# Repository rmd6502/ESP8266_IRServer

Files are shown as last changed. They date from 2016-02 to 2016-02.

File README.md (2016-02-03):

ESP8266 IR Throwie
==================

This takes the concept of the TV-B-Gone one step further
by allowing the device to be controlled with Wifi.

This version hardcodes the wifi parameters, but a future version
will allow use as an Access Point to set up wifi.

You'll need [my fork](https://github.com/rmd6502/IRremoteESP8266) of the IRRemote ESP8266 
library for the Dyson remote protocol support.

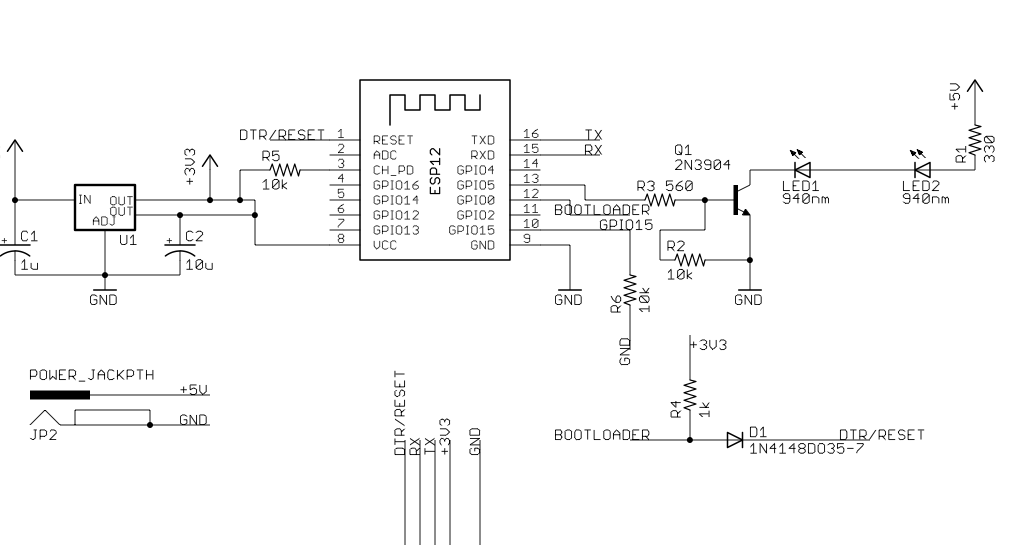
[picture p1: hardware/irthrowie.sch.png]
schematic


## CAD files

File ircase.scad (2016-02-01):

$fn=40;
board_width = 32.72;
board_length = 54.61;
board_height = 2;

module bottom() {
    union() {
        difference() {
            translate([-6.5,-3,0]) cube([42,64,10]);
            translate([-5.5,-2,1]) cube([40,62,9.1]);
            // four mounting screws
            translate([-3.5,1,-0.1]) cylinder(d=3, h=1.2);
            translate([-3.5,49,-0.1]) cylinder(d=3, h=1.2);
            translate([33,1,-0.1]) cylinder(d=3, h=1.2);
            translate([33,49,-0.1]) cylinder(d=3, h=1.2);
            // cutout for power
            translate([-6.6,0,5]) minkowski() {
                cube([2,11,6]);
                rotate([0,90,0]) cylinder(d=2,h=2);
            }
        }
        // mount board to case
        translate([17.55,2.6,1]) difference() {
            cylinder(d=5,h=4);
            cylinder(d=2.8,h=4.1);
        }
        // mount board to case
        translate([28.85,39.4,1]) difference() {
            cylinder(d=5,h=4);
            cylinder(d=2.8,h=4.1);
        }
        //translate([-1.75,0,5]) cube([board_width, board_length, board_height]);
        
        // screwhole for top
        translate([-4,30,0.9]) difference() {
            cylinder(h=9.1,d=4);
            translate([0,0,4]) cylinder(h=5.2,d=2.5);
        }
        translate([33,30,0.9]) difference() {
            cylinder(h=9.1,d=4);
            translate([0,0,4]) cylinder(h=5.2,d=2.5);
        }
    }
}

module top() {
    union() {
        difference() {
            translate([-6.5,-3,14]) cube([42,64,1.3]);
            translate([25.05,5.3,12]) led();
            translate([25.05,12.8,12]) led();
            // Design for the top - deliberately not included
            rotate([0,0,90]) translate ([15.6,53,14.6]) linear_extrude(0.8) resize([35,0,0],auto=true) import("zenith_1937.dxf");
            translate([-4,30,13.9]) cylinder(h=1.5,d=2.7);
            translate([33,30,13.9]) cylinder(h=1.5,d=2.7);
        }
        difference() {
            translate([-5,-1.5,13]) cube([39.5,61.5,1]);
            translate([-4,-0.5,12.9]) cube([37.5,59.5,1.2]);
            translate([-4,30,12.9]) cylinder(h=1.3,d=4.2);
            translate([33,30,12.9]) cylinder(h=1.3,d=4.2);
        }
    }
}

module led() {
    union() {
        cylinder(h=6.1, r=2.6);
        translate([0,0,6.1]) sphere(r=2.6);
        difference() {
            cylinder(r=3.1,h=1);
            translate([2.6, -3, -.1]) cube([2,6,1.2]);
        }
    }
}

bottom();

top();

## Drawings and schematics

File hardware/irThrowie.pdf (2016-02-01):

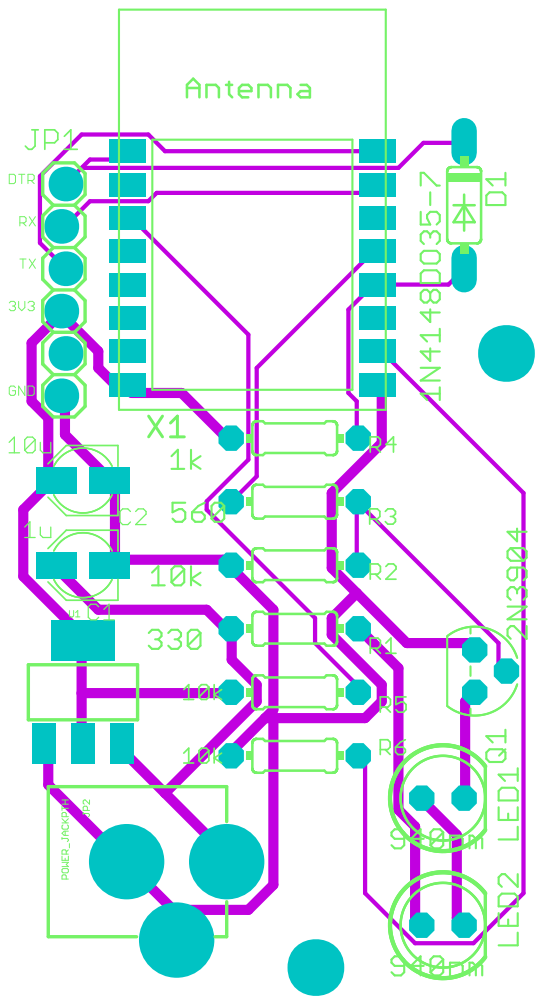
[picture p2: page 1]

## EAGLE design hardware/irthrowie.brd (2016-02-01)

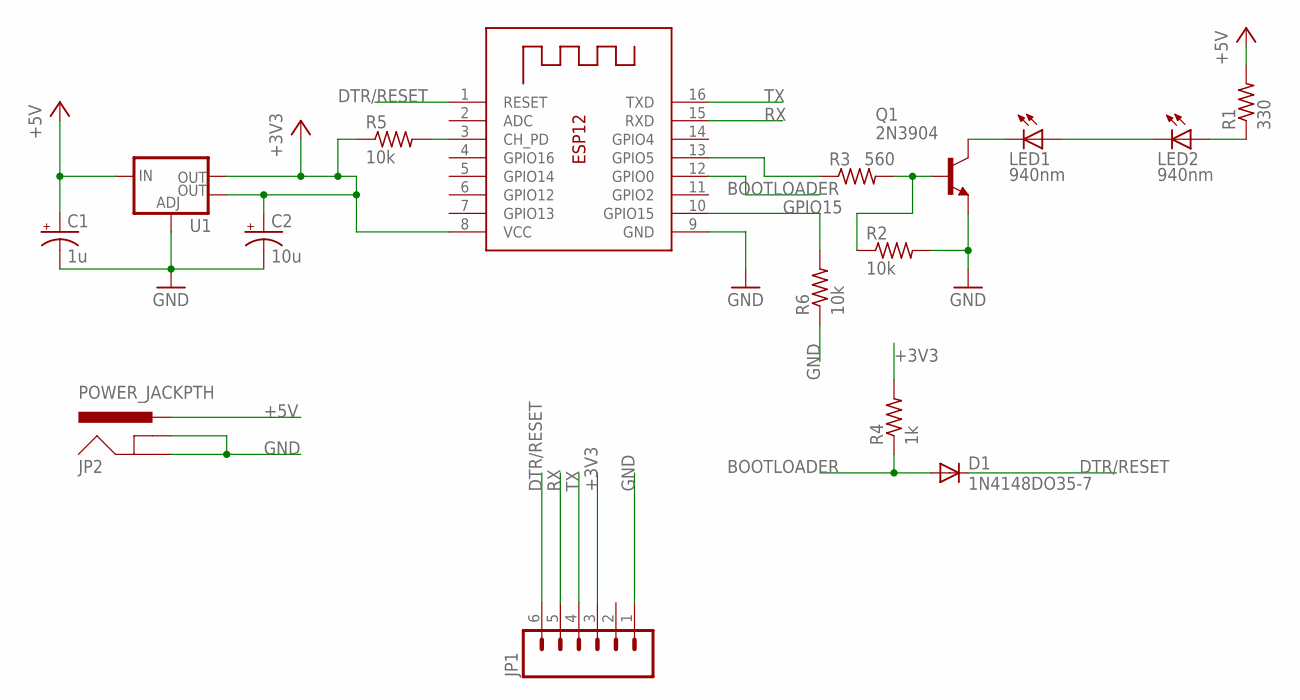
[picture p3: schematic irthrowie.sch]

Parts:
C1: 1u; PANASONIC_B
C2: 10u; PANASONIC_B
D1: 1N4148DO35-7; DO35-7
JP1: M06LOCK; 1X06_LOCK
JP2: POWER_JACKPTH; POWER_JACK_PTH
LED1, LED2: 940nm; LED5MM
Q1: 2N3904; TO92
R1: 330; 0204/7
R2, R5, R6: 10k; 0204/7
R3: 560; 0204/7
R4: 1k; 0204/7
U1: V_REG_LM1117SOT223; SOT223
X1: ESP-12

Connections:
+3V3: C2.+, JP1.3, R4.2, R5.1, U1.2 (OUT), U1.4 (OUT), X1.8 (VCC)
+5V: C1.+, JP2.PWR, R1.2, U1.3 (IN)
BOOTLOADER: D1.A, R4.1, X1.12 (GPIO0)
DTR/RESET: D1.C, JP1.6, X1.1 (RESET)
GND: C1.-, C2.-, JP1.1, JP2.GND, JP2.GNDBREAK, Q1.3 (E), R2.2, R6.1, U1.1 (ADJ), X1.9 (GND)
GPIO15: R6.2, X1.10 (GPIO15)
unnamed: LED1.A, LED2.K (C)
unnamed: Q1.2 (B), R2.1, R3.2
unnamed: LED1.K (C), Q1.1 (C)
unnamed: LED2.A, R1.1
unnamed: R5.2, X1.3 (CH_PD)
unnamed: R3.1, X1.13 (GPIO5)
RX: JP1.5, X1.15 (RXD)
TX: JP1.4, X1.16 (TXD)

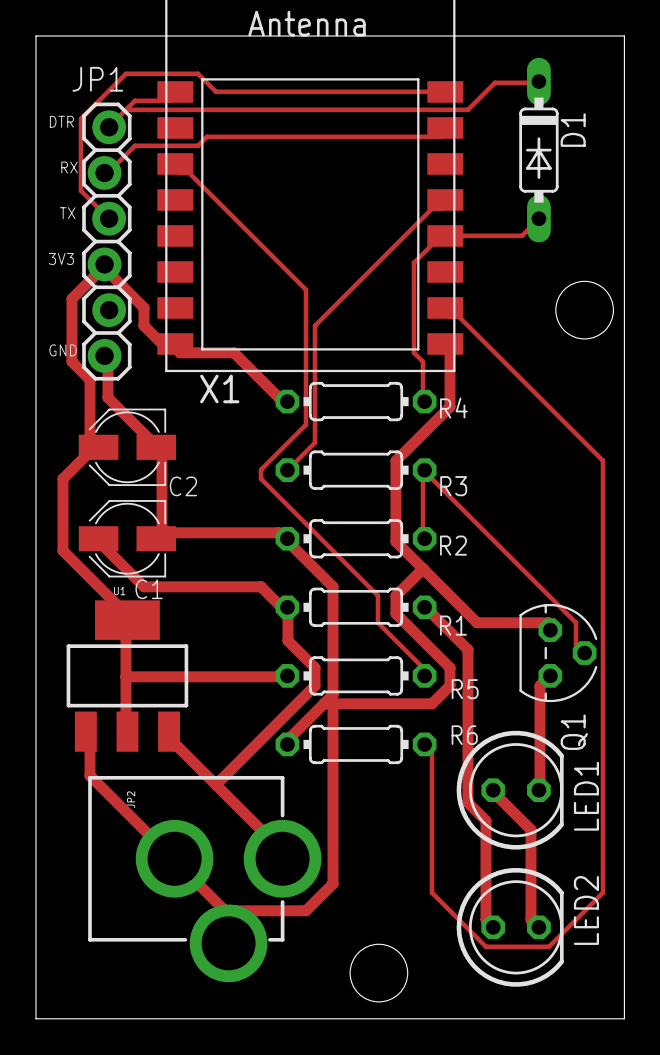
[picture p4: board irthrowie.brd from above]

Board: 2 copper layers, 32.7 x 54.6 mm, 16 parts (0 on the bottom side), 14 nets.

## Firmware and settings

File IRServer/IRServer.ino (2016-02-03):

/*
 * IRremoteESP8266: IRServer - demonstrates sending IR codes controlled from a webserver
 * An IR LED must be connected to ESP8266 pin 0.
 * Version 0.1 June, 2015
 */

#include <ESP8266WiFi.h>
#include <WiFiClient.h>
#include <ESP8266WebServer.h>
#include <ESP8266mDNS.h>
#include <IRremoteESP8266.h>
#include <limits.h>
 
const char* ssid = "***";
const char* password = "***";
MDNSResponder mdns;

ESP8266WebServer server(80);

IRsend irsend(5);

void handleRoot() {
 server.send(200, "text/html", 
  "<html><head>"
  "<title>ESP8266 Demo</title>"
  "</head>"
  "<body>"
    "<h1>Hello from ESP8266, you can send IR signals from here!</h1>"
    "<form action=\"/ir\">"
      "<select name=\"protocol\">"
        "<option value=\"NEC\">NEC</option>"
        "<option value=\"Dyson\">Dyson</option>"
      "</select>"
      "<input type=\"text\" name=\"code\" />"
      "<input type=\"submit\" />"
    "</form>"
  "</body></html>");
}

void handleIr(){
  int repeats = 0;
  unsigned long code = ULONG_MAX;
  unsigned int protocol = NEC;
  for (uint8_t i=0; i<server.args(); i++){
    if(server.argName(i) == "code") 
    {
      //unsigned long code = server.arg(i).toInt();
      code = strtoul(server.arg(i).c_str(), NULL, 0);
      Serial.print("request "); Serial.println(code, HEX);
    }
    else if(server.argName(i) == "repeat")
    {
      repeats = server.arg(i).toInt();
    } 
    else if (server.argName(i).substring(0,5) == "proto") {
      for (int count = 0; count < NUM_DECODE_TYPES; ++count) {
        if (decode_names[count] == server.arg(i)) {
          protocol = count;
          break;
        }
      }
    }
  }
  if (code != ULONG_MAX && protocol > 0) {
    switch(protocol) {
      case NEC: sendNECProtocol(code, repeats); break;
      case DYSON: sendDysonProtocol(code); break;
      default: break;
    }
  }
  handleRoot();
}

void handleNotFound(){
  String message = "File Not Found\n\n";
  message += "URI: ";
  message += server.uri();
  message += "\nMethod: ";
  message += (server.method() == HTTP_GET)?"GET":"POST";
  message += "\nArguments: ";
  message += server.args();
  message += "\n";
  for (uint8_t i=0; i<server.args(); i++){
    message += " " + server.argName(i) + ": " + server.arg(i) + "\n";
  }
  server.send(404, "text/plain", message);
}
 
void setup(void){
  irsend.begin();
  
  Serial.begin(115200);
  WiFi.begin(ssid, password);
  Serial.println("");

  // Wait for connection
  while (WiFi.status() != WL_CONNECTED) {
    delay(500);
    Serial.print(".");
  }
  Serial.println("");
  Serial.print("Connected to ");
  Serial.println(ssid);
  Serial.print("IP address: ");
  Serial.println(WiFi.localIP());
  
  if (mdns.begin("irserver1", WiFi.localIP())) {
    Serial.println("MDNS responder started");
  }
  
  server.on("/", handleRoot);
  server.on("/ir", handleIr); 
 
  server.on("/inline", [](){
    server.send(200, "text/plain", "this works as well");
  });

  server.onNotFound(handleNotFound);
  
  server.begin();
  Serial.println("HTTP server started");
}
 
void loop(void){
  server.handleClient();
} 

void sendNECProtocol(uint32_t code, int repeats)
{
    uint32_t protoCode = 0;
    //for each byte, reverse the bits, then send the byte + the inverse
    uint8_t topByte = reverseBits(code >> 8UL);
    protoCode = (uint32_t)topByte << 24UL;
    protoCode |= (((uint32_t)~topByte & 0xff) << 16UL);
    uint8_t bottomByte = reverseBits(code & 0xff);
    protoCode |= ((uint32_t)bottomByte << 8UL);
    protoCode |= ((uint32_t)~bottomByte & 0xff);
    Serial.print("result code ");
    Serial.println(protoCode,HEX);
    irsend.sendNEC(protoCode, 32, repeats);
}

void sendDysonProtocol(uint16_t code)
{
  static uint8_t count = 0;
  code = code << 2 + count;
  irsend.sendDyson(code, 15);
  count = (count + 1) & 3;
}

uint8_t reverseBits(uint16_t byteval) 
{
    uint8_t result = 0;
    for (int bitnum = 0; bitnum < 8; ++bitnum) {
        result = (result << 1UL) | (byteval & 1UL);
        byteval >>= 1UL;
    }
    return result;
}

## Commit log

2016-02-01 first rev
    [irthrowie.brd, irthrowie.sch]
2016-02-01 add case design
    [ircase.scad]
2016-02-02 add schematic

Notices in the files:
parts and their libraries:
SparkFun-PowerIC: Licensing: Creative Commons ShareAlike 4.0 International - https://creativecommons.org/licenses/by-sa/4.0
